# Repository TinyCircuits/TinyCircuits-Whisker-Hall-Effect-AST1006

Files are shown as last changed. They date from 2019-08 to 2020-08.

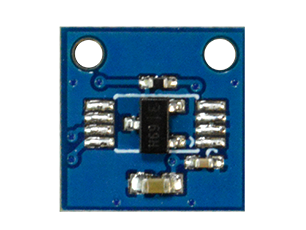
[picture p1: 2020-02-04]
images/AST1006-D-Learn-Photo-01.png

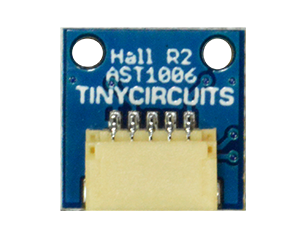
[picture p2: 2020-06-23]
images/AST1006-A-Learn-Photo-02.png

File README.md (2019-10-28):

# TinyCircuits-Wireling-Hall-Effect
# AST1006 Rev2

The design files are located under design_files/ for the TinyCircuits AST1006 Rev 2 PCB. This is a Wireling board which is either populated for digital or analog magnetic readings.

The digital variant features a humble TCS40DLR hall effect switch with High/Low output and a switching point near 3.5mT (35 Gauss) and 1.4mT (14 Gauss) of Hysteresis built in.

The analog version features the Allegro A1454 linear hall effect sensor with 12-bit output and built in temperature compensation. This sensor works best with Ferrite type magnets.

Format is in Cadsoft Eagle format - Eagle version 6.2 was used for the original design.

For more infomation on this, check out the product page at TinyCircuits.com

# License:

Design by TinyCircuits.
All design files are released under the Creative Commons Attribution Share-Alike 3.0 License, see the following link for details: http://creativecommons.org/licenses/by-sa/3.0

All text above must be included in any redistribution or derived design

This project uses designs and concepts developed as part of the Arduino project and the LilyPad project.  The TinyCircuits design files themselves (schematics, PCB and libraries) are not directly derived from these works' design files and have been created new, however the concepts and basic architecture behind the TinyDuino and TinyLily products are derived and we thank the hard work of the organizations below for their contributions to open-source hardware:
  
Original Arduino Uno Design by Team Arduino

LilyPad Arduino Design by Leah Buechley and Sparkfun Electronics

Please support the open-source hardware community

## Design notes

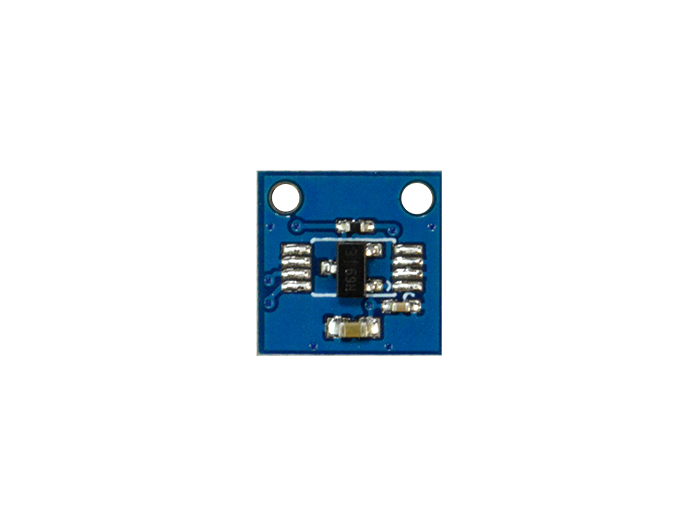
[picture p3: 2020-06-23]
images/AST1006-D-Product-Photo-01.png

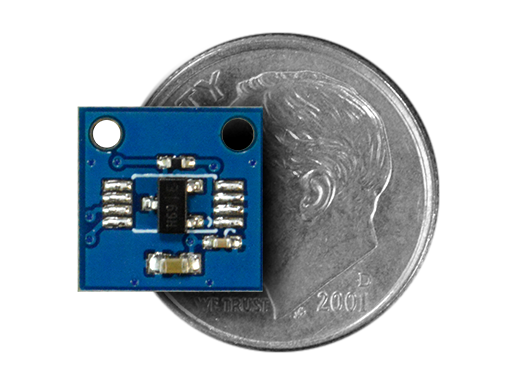
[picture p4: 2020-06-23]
images/AST1006-D-Product-Photo-03.png

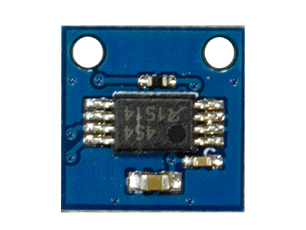
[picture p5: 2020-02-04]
images/AST1006-A-Learn-Photo-01.png

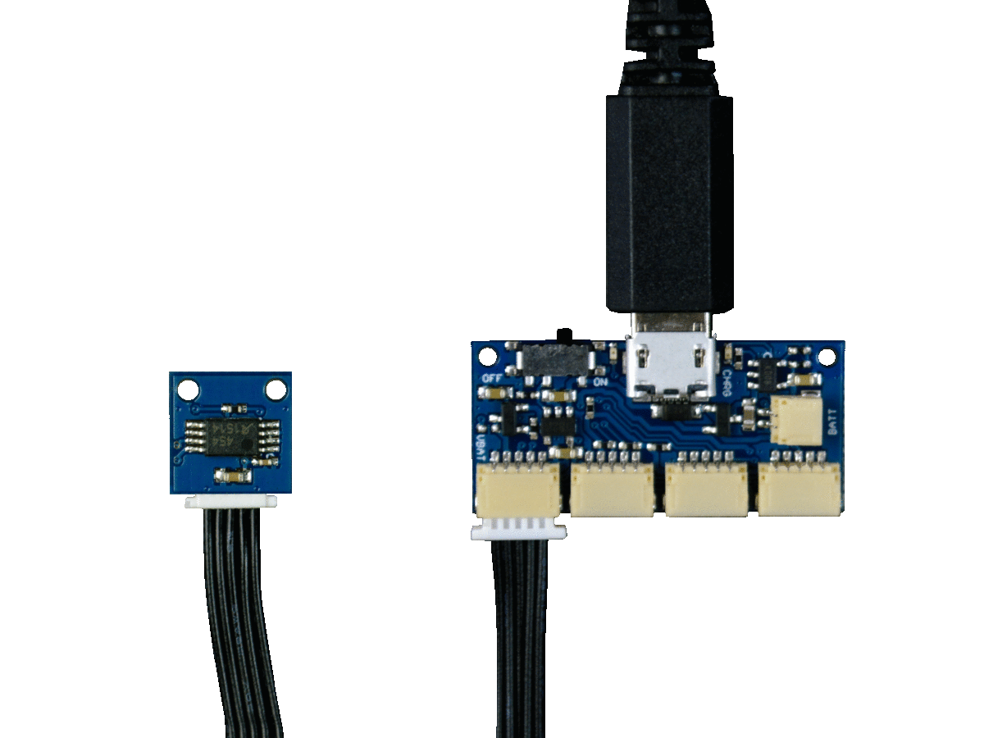
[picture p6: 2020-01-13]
images/AST1006-Animation-02.gif

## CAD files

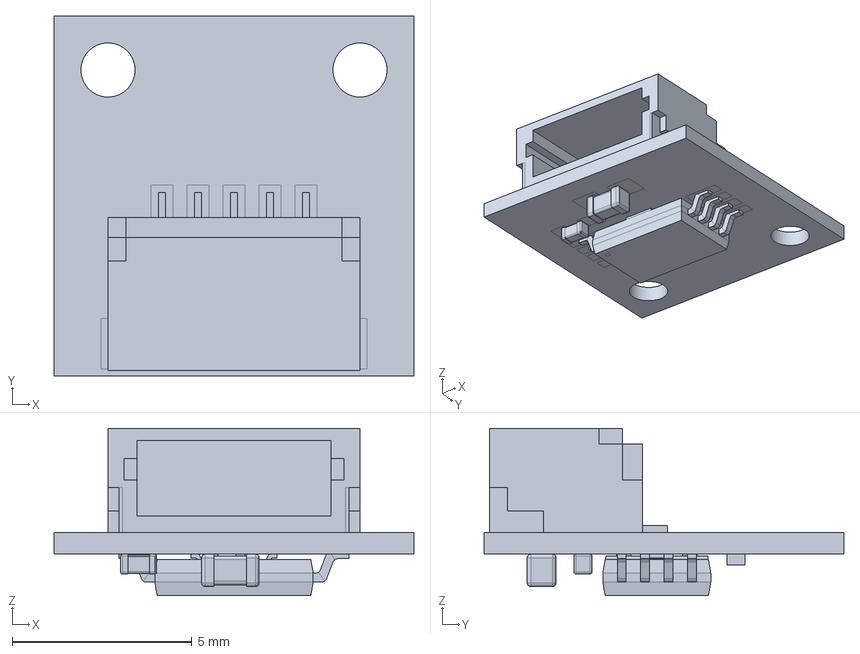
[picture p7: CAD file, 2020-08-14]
cad/Wireling_HALL_AST1006_REV2-IGES.iges
10.0 x 10.0 x 4.65 mm

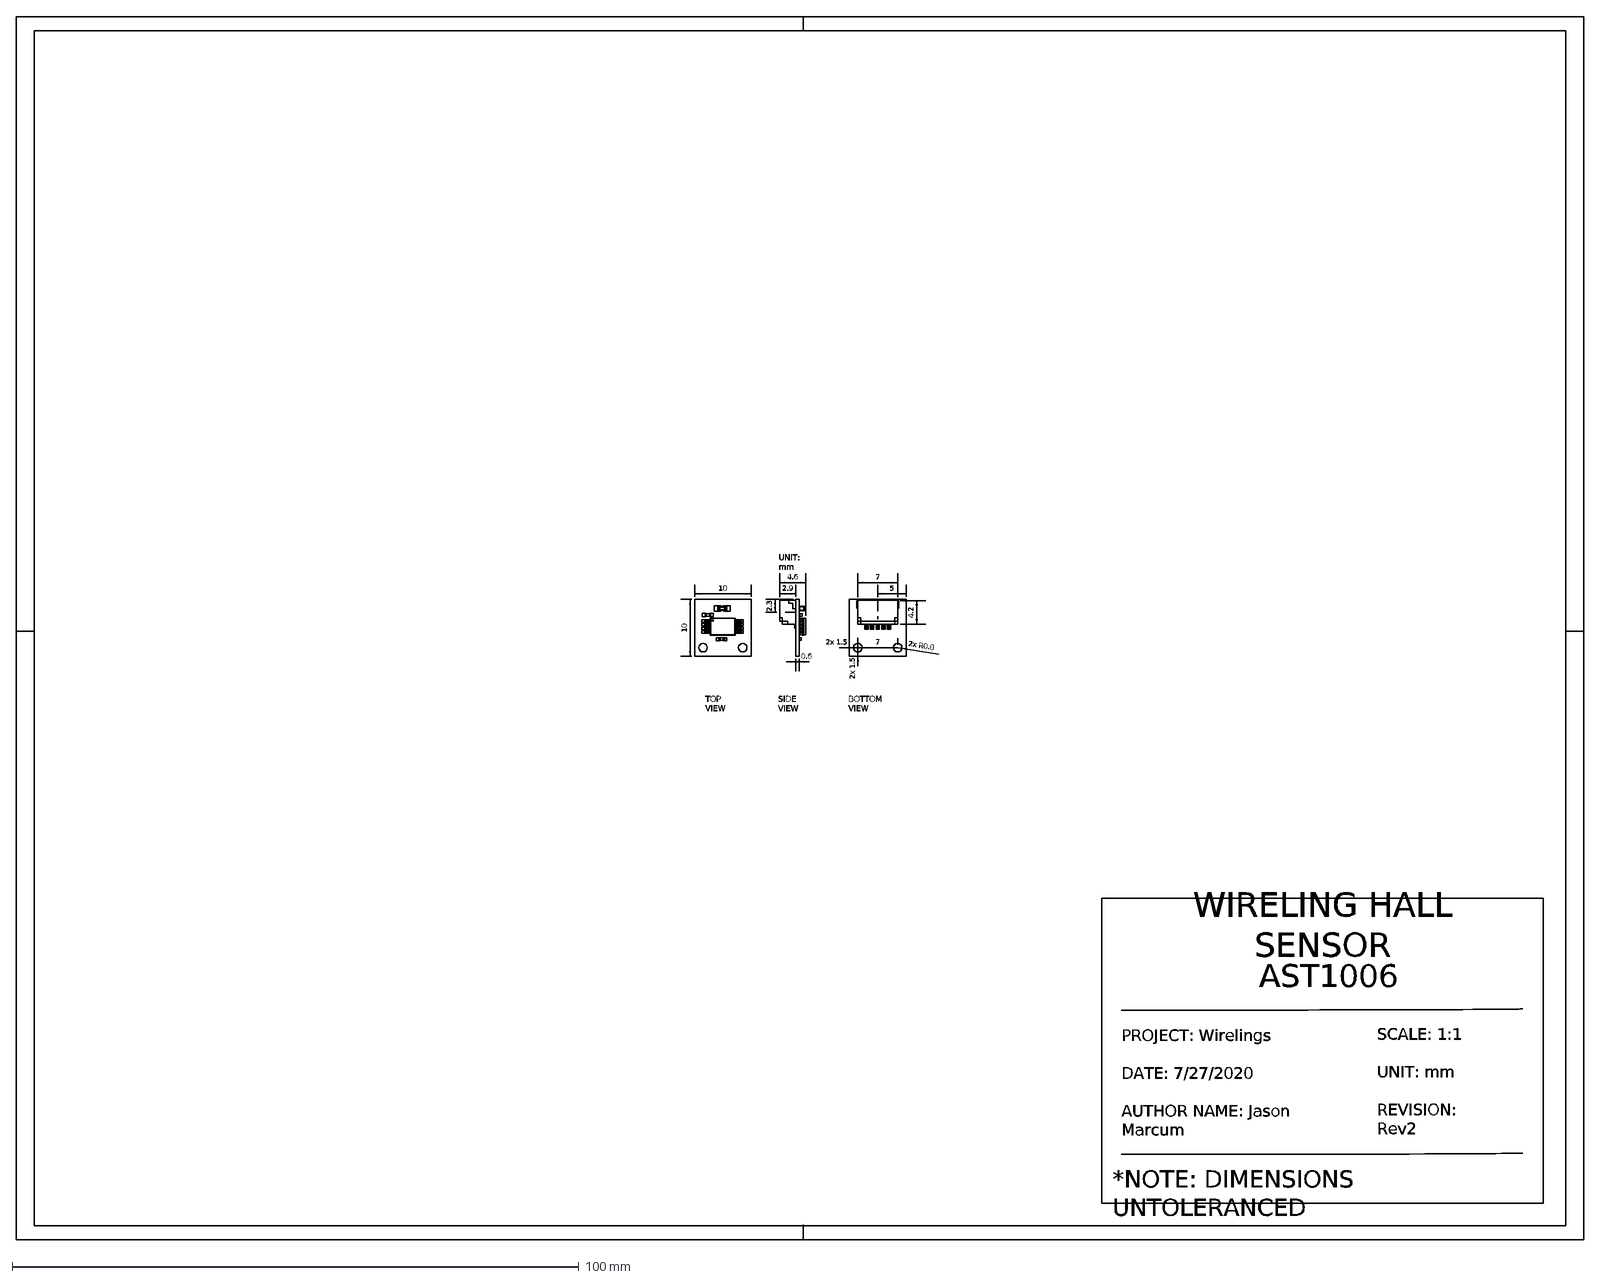
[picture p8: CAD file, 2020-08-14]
cad/Wireling_HALL_AST1006_REV2-DETAILED_DRAWING-DXF.dxf
*NOTE: DIMENSIONS UNTOLERANCED
10
2.9
4.6
0.6
2x 1.5
7
5
4.2
2x R0.8
TOP VIEW
BOTTOM VIEW
SIDE VIEW
UNIT: mm
WIRELING HALL SENSOR
AST1006
SCALE: 1:1 UNIT: mm REVISION: Rev2
2.3
PROJECT: Wirelings DATE: 7/27/2020 AUTHOR NAME: Jason Marcum

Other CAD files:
cad/Wireling_HALL_AST1006_REV2-STL.stl
cad/Wireling_HALL_AST1006_REV2-STEP.step

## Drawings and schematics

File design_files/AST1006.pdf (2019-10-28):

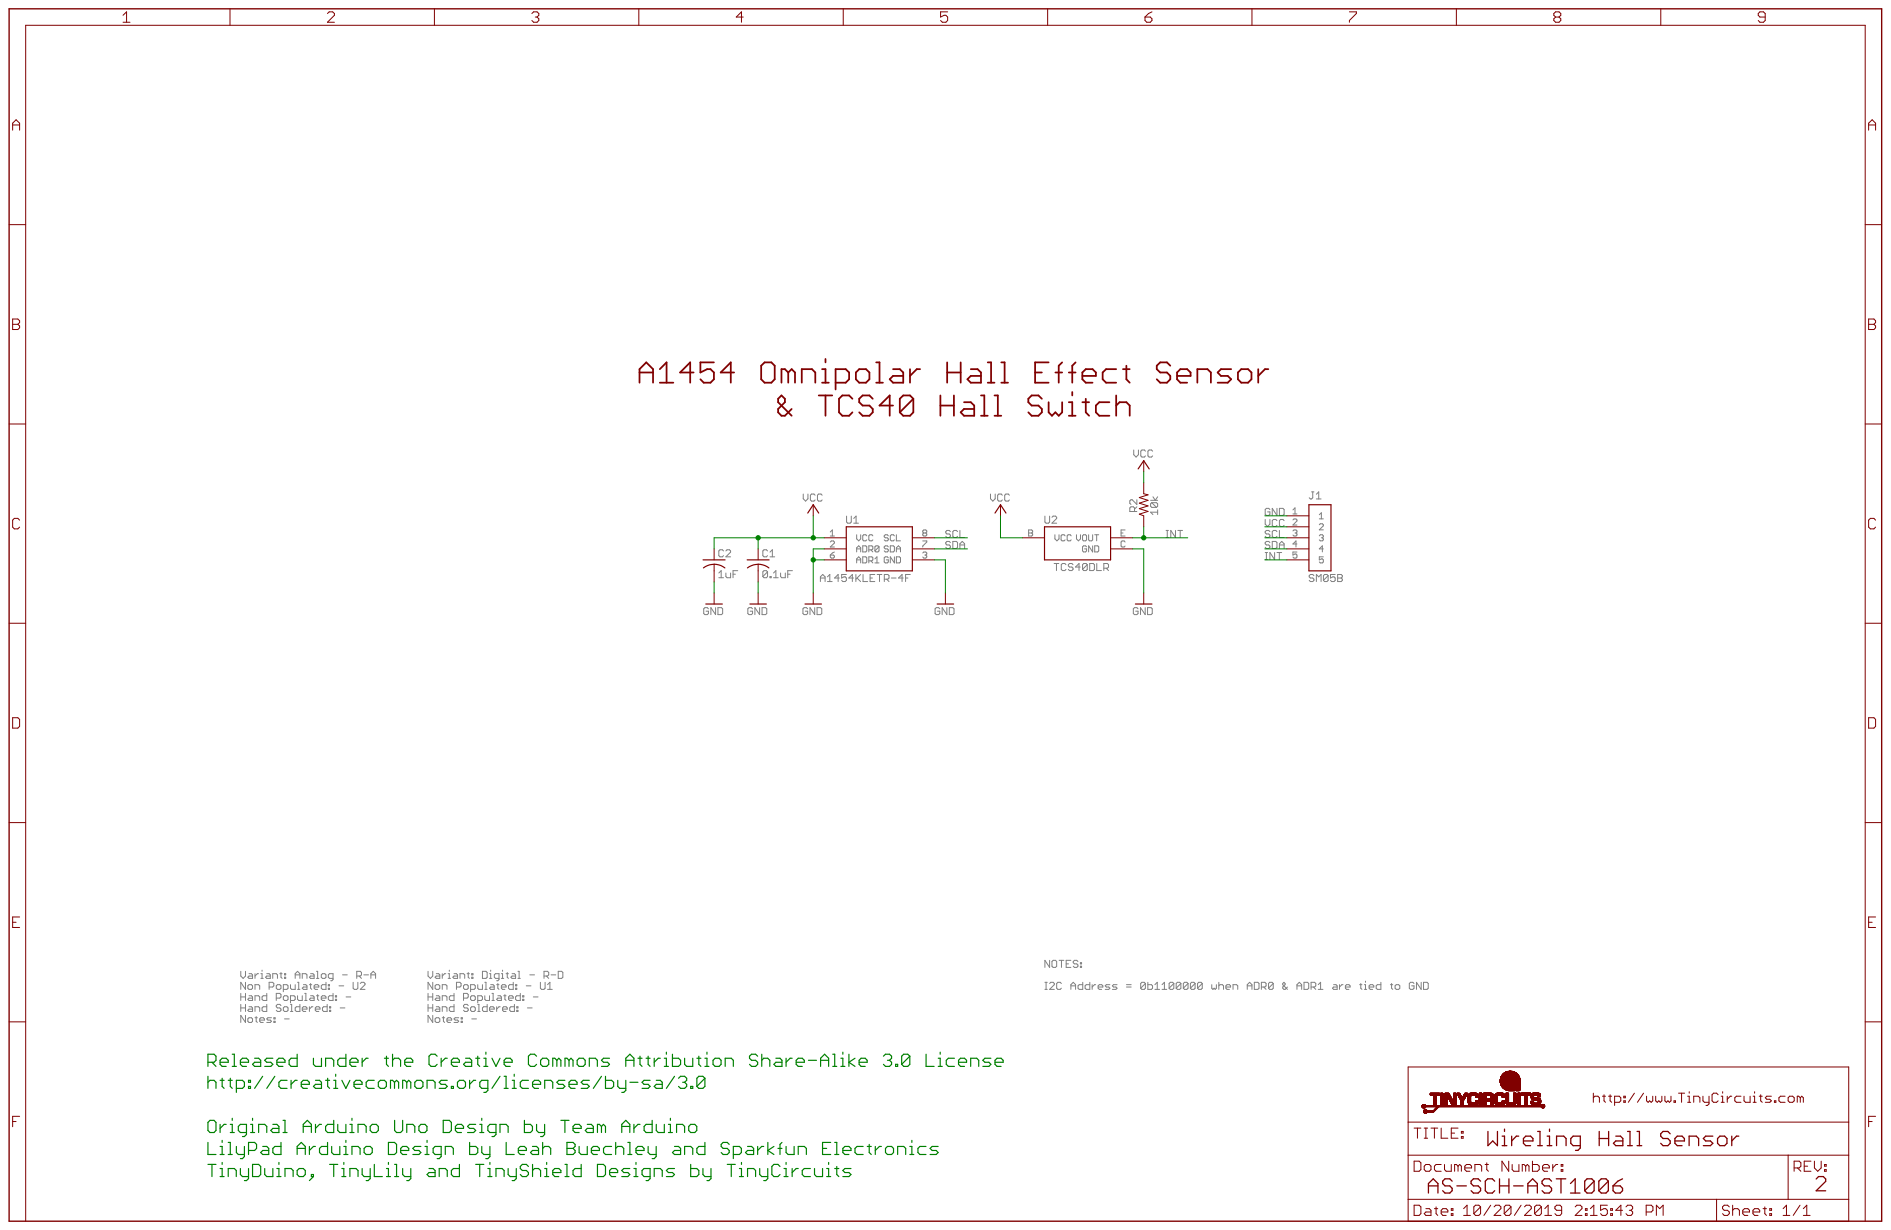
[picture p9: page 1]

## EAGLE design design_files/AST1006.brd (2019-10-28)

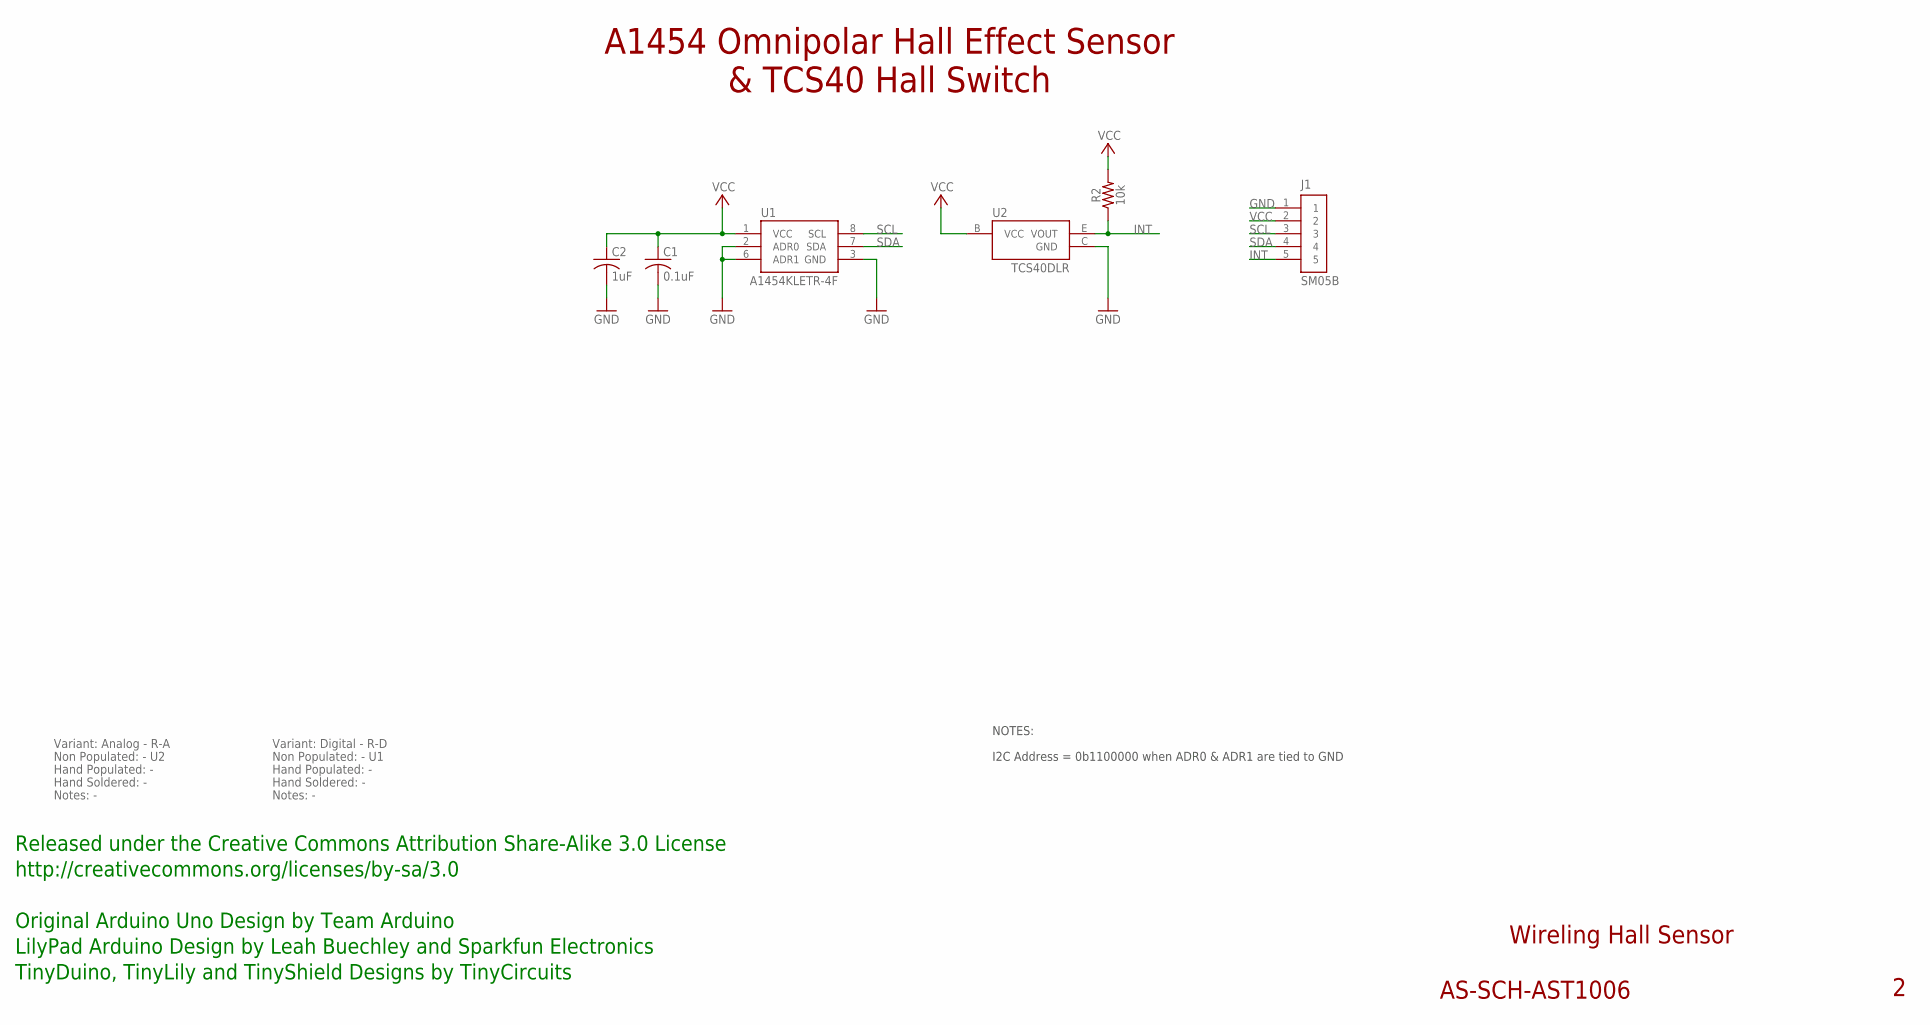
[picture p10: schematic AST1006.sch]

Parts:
C1: 0.1uF; C0402
C2: 1uF; C0603; PARTNO AS-ITM-00410
J1: SM05B; JST_SH_5X1_EDGE
R2: 10k; 0402; PARTNO AS-ITM-00032
U1: A1454KLETR-4F; TSSOP(8)
U2: TCS40DLR; SOT23A

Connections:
GND: C1.2, C2.2, J1.1, U1.2 (ADR0), U1.3 (GND), U1.6 (ADR1), U2.C (GND)
INT: J1.5, R2.1, U2.E (VOUT)
SCL: J1.3, U1.8 (SCL)
SDA: J1.4, U1.7 (SDA)
VCC: C1.1, C2.1, J1.2, R2.2, U1.1 (VCC), U2.B (VCC)

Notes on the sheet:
Wireling Hall Sensor
AS-SCH-AST1006
A1454 Omnipolar Hall Effect Sensor
Released under the Creative Commons Attribution Share-Alike 3.0 License
http://creativecommons.org/licenses/by-sa/3.0
Original Arduino Uno Design by Team Arduino
TinyDuino, TinyLily and TinyShield Designs by TinyCircuits
LilyPad Arduino Design by Leah Buechley and Sparkfun Electronics
NOTES:
I2C Address = 0b1100000 when ADR0 & ADR1 are tied to GND
& TCS40 Hall Switch
Non Populated: - U2
Hand Populated: -
Hand Soldered: -
Variant: Analog - R-A
Notes: -
Non Populated: - U1
Variant: Digital - R-D

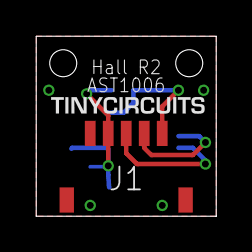
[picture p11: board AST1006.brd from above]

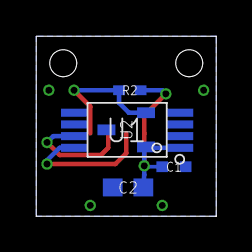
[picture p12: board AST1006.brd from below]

Board: 2 copper layers, 10.0 x 10.0 mm, 7 parts (5 on the bottom side), 5 nets.

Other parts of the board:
U$1: DOCFIELD-TINYCIRCUITS-PCB

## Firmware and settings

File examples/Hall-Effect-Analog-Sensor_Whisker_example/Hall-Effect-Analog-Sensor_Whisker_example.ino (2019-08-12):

/*************************************************************************
 * A1454 Whisker Test Code - 
 * This program will show the basic method of interfacing with the sensor 
 * by printing out the Analog values (readings from 0 to 4096 (12-bit)) on
 * a TinyScreen+ and the Serial Monitor.
 * 
 * Hardware by: TinyCircuits
 * Written by: Laverena Wienclaw for TinyCircuits
 * 
 * Initiated: Mon. 6/20/2018
 * Updated: Tue. 07/03/2018
 ************************************************************************/
#include <Wire.h>               // For I2C communication
#include <TinyScreen.h>         // For the TinyScreen+
#include "TinyCircuits_A1454.h" // For the sensor

// Variables the for the TinyScreen+ and its background
TinyScreen display = TinyScreen(TinyScreenPlus);
int background = TS_16b_Black;

// A sensor object, the methods will be used to interface with the A1454
TinyCircuits_A1454 hall = TinyCircuits_A1454();

// The power pin for the Whisker Adapters
const int powerPin = 4;

void setup() {
  // Begin communication 
  SerialUSB.begin(9600);
  SerialUSB.println("HALL LIBRARY TEST CODE");
  Wire.begin();
  
  pinMode(powerPin, OUTPUT);
  digitalWrite(powerPin, HIGH);

  // Setup and style for TinyScreen+
  display.begin();
  display.setFlip(true);
  display.setBrightness(15);
  display.setFont(thinPixel7_10ptFontInfo);

  selectPort(0); // This must match the port the Whisker is connected to 
                 // on the Adapter board
  hall.begin();
//  hall.wake(); 
}

void loop() {
  long mag = hall.readMag();
  long temp = hall.readTemp();
  long mode = hall.readMode();

  if (mode == 0) SerialUSB.print("AWAKE\t\t");
  else if (mode == 1) SerialUSB.print("SLEEPING\t\t");

  SerialUSB.print("Mag: ");
  SerialUSB.print(mag);
  SerialUSB.print("mW");
  SerialUSB.print('\t');

  SerialUSB.print("TempF: ");
  int tempF = ((temp * 1.8) + 32);
  SerialUSB.print(tempF);
  SerialUSB.print("°F");
  SerialUSB.print('\t');

  SerialUSB.print("TempC: ");
  SerialUSB.print(temp);
  SerialUSB.println("°C");
//  hall.sleep();
  delay(250); // Makes TinyScreen+ updates prettier

  printToScreen(mag, temp, mode);
  //updateLeds(mag);
}

// **This function is necessary for all Whisker boards attached through an Adapter board**
// Selects the correct address of the port being used in the Adapter board
void selectPort(int port) {
  Wire.beginTransmission(0x70);
  Wire.write(0x04 + port);
  Wire.endTransmission();
}

// Prints the hall sensor values to the TinyScreen+
void printToScreen(int mag, int temp, int mode) {
  // This will make the screen look a little unsteady but is needed in order
  // to clear old values 
  display.clearScreen();

  display.fontColor(TS_8b_White, background);
  display.setCursor((48 - (display.getPrintWidth("Linear Hall Test")) / 2), 0);
  display.print("Linear Hall Test");
  
  display.fontColor(TS_8b_Blue, background);
  display.setCursor(0, 16);
  display.print("Mag = ");
  display.print(mag);

  display.fontColor(TS_8b_Red, background);
  display.setCursor(0, 28);
  display.print("TempC = ");
  display.print(temp);

  display.fontColor(TS_8b_Green, background);
  display.setCursor(0, 40);
  display.print("Mode = ");
  display.print(mode);
}

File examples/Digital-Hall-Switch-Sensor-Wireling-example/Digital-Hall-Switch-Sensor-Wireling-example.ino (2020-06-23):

/*************************************************************************
 * TCS40 Hall Switch Sensor Wireling Tutorial:
 * This program prints the status of a magnet detected or not using a 
 * TCS40 Digital Hall Switch Wireling.
 * 
 * Hardware by: TinyCircuits
 * Code by: Laveréna Wienclaw for TinyCircuits
 *
 * Initiated: 09/27/2019
 * Updated: 12/04/2019
 ************************************************************************/

#include <Wireling.h> // For interfacing with Wirelings

// Hall Sensor variables
#define magPin A0        // Corresponds to PORT# of Wireling used (Do not use A0)
bool hallOutput = 0;     // What is directly output from Wireling
bool magnetDetected = 0; // Make sense of output 

// Make Serial Monitor compatible for all TinyCircuits processors
#if defined(ARDUINO_ARCH_AVR)
  #define SerialMonitorInterface Serial
#elif defined(ARDUINO_ARCH_SAMD)
  #define SerialMonitorInterface SerialUSB
#endif

void setup() {
  SerialMonitorInterface.begin(9600);
  
  // Enable & power Wireling
  Wireling.begin();

  // Set Hall Switch Pin to input
  pinMode(magPin, INPUT);
}

void loop() {
  hallOutput = digitalRead(magPin); // If no magnet, hallOutput == 1
  magnetDetected = !hallOutput; // Flip the hallOutput so magnetDetected == 1 when there is a magnet
  
  SerialMonitorInterface.println(magnetDetected);
}

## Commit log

2019-10-28 name updates
    [AST1006.brd, AST1006.sch]
2019-12-17 updated documentation
    [AST1006.sch]
2020-06-23 update hall switch code to work with TinyDuino
2020-08-14 Add CAD data
    [Wireling_HALL_AST1006_REV2-DETAILED_DRAWING-DXF.dxf, Wireling_HALL_AST1006_REV2-IGES.iges, Wireling_HALL_AST1006_REV2-STEP.step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]
